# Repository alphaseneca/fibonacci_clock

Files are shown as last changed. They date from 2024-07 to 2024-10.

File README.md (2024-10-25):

<!-- # fibonacci_clock

A unique clock that uses the Fibonacci sequence to display time with colored squares, combining math and art in an innovative timekeeping design.

## Working

It works by lighing up a segment of the matrix based on the time in the Fibonacci sequence. If the time is 6:42 it will light up the segment **1** and **5** to **RED** which will add to give the hour 6. And for minutes it will light up the segment **3** and **5** to **BLUE** which will add to **8*5** equals to **40** minutes. And since the segment **5** are lit by both the hour and minutes it will change the colour to **GREEN** to show the overlap in the both hour and minutes.

> The segment can only represent between **1 - 12** and to represent the minutes we are multiplying it by 5.
> Since the increments are in every 5 minutes thus the time can be between **40 - 45** Minutes.

![fibonacci_clock](images/fibonacci_clock_working.jpg)

Working Image:
![fibonacci_clock](images/Image1.jpg)
 -->

# Fibonacci Clock

A unique clock project that combines **math and electronics** using the Fibonacci sequence to display time with colored segments. Powered by a **Wemos D1 Mini**, it fetches the current time using **NTP**. This repository serves as a **learning journal**, tracking the development process, inspirations, troubleshooting, and future improvements.

---

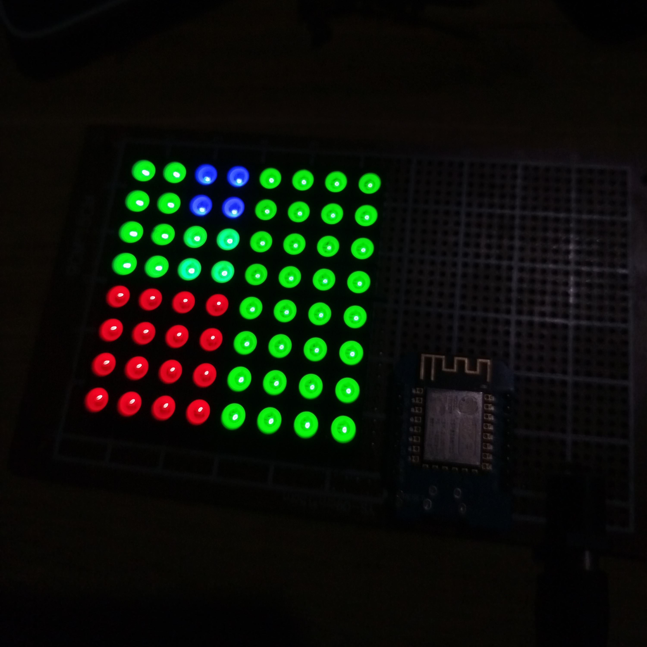
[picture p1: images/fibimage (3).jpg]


---

## Repository Structure

- **`images/`**: Photos of the clock and its working principle.
- **`fibonacci_clock_code/`**: Contains the code to run the Fibonacci clock logic.
<!-- - **`References/`**: Resources and ideas that inspired the project.   -->
- **`fibonacci_clock_pcb/`**: Files and documentation for the PCB design.
- **`debugging/`**: Logs of issues encountered and solutions applied during development.
<!-- - **`Inspiration.md`**: Notes on inspirations and design choices, with references for future enhancements. -->

---

## How It Works

The Fibonacci Clock displays time by lighting up segments of a matrix corresponding to Fibonacci numbers.

- **Microcontroller**: Wemos D1 Mini (ESP8266).
- **Time Sync**: Fetches the current time via **NTP** (Network Time Protocol).
- **Hour Representation**:  
  Example: If the time is **6:42**, segments **1** and **5** are lit **RED**, which sum to **6** for the hour.
- **Minute Representation**:  
  For **42 minutes**, segments **3** and **5** are lit **BLUE**, resulting in **(3 + 5) × 5 = 40 minutes**.
- **Overlap**:  
  When a segment represents both hours and minutes (e.g., segment **5**), it is lit **GREEN** to indicate overlap.

**Working Principle Diagram**:  
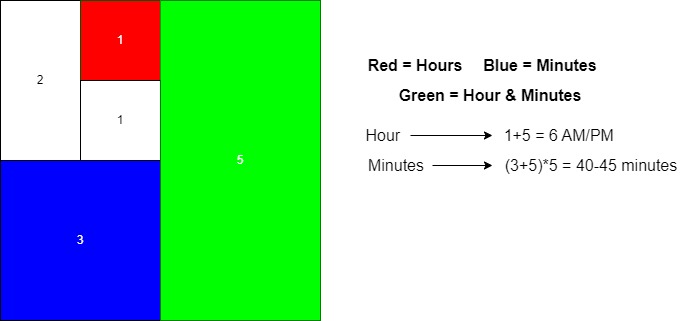
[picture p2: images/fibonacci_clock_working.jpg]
Fibonacci Clock Working
 

> Segments only represent numbers between **1 - 12**, and minute values are scaled by **multiplying by 5**.  
> Time increments are in 5-minute intervals, so valid minute values range between **40 - 45 minutes**.

---

## The Journey So Far

Building this clock has been an exciting adventure. It started as a simple idea to make a desktop artpiece that is bit unique and looks cool and ended up being a timekeeping device. Using the **Wemos D1 Mini** to sync time with NTP added complexity but opened new possibilities.

 <!-- Handling **network connectivity** and **color overlaps** provided valuable learning experiences. -->

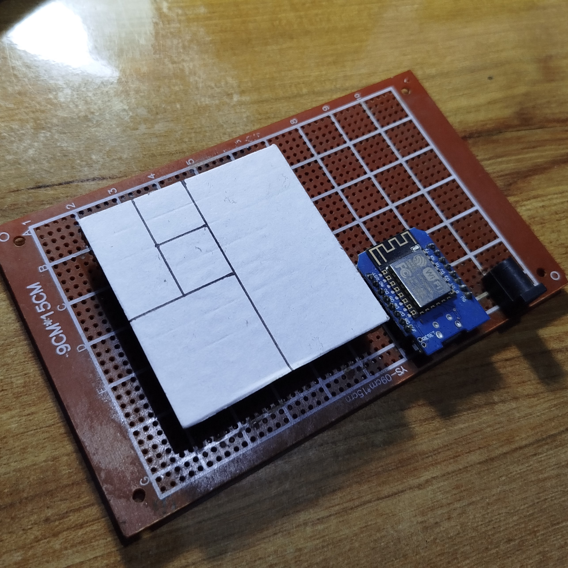
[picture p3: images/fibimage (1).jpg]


Creating the PCB design was also a journey in its own. I started with the prefboard and the main project is still on the prefboard but for the further development and to make the device look clean and more presentable the [PCB design](fibonacci_clock_pcb/fibonacci_clock_pcb.jpg) was created.

The pcb that I created is not complete. It is still a work in progress and nowhere near to the original design. I am planning to make the project like the main original design itself.

Future iterations may include **offline timekeeping** by integrating an **RTC module** to eliminate reliance on NTP. Wireless control and animations are also on the horizon!

---

## Debugging Log

- **Issue 1**: Incorrect color when hours and minutes overlapped.
  - **Solution**: Modified the RGB blending logic to correctly show GREEN for overlaps.
- **Issue 2**: Incorrect minute calculation when sum exceeded valid range.
  - **Solution**: Added checks to restrict values between 0-12 for valid Fibonacci sums.
- **Issue 3**: The light is not bright enough and flickers a lot.
  - **Solution**: Removed the delay in the main loop to reduce flickering.
    > Just a current solution though. Planning to remove the second solution in the future busing **MAX7219** chip rather than the **LM74HC595** chip.

---

## Future Improvements

- **RTC Integration**: Add an **RTC module** (like DS3231) for offline timekeeping.
- **PCB Enhancements**: Optimize the layout for smaller size and better wiring.
- **Dynamic Patterns**: Add animations or interactive light sequences. There could be much more animations and the rgb led can be used to show some patterns.
- **Battery Power**: Implement battery-powered functionality for portability.

---

## References and Inspirations

- Original inspiration from the [Kickstarter Campaign](https://www.kickstarter.com/projects/basbrun/fibonacci-clock-an-open-source-clock-for-nerds-wit).
- Building process from [Instructables project](https://www.instructables.com/The-Fibonacci-Clock/).
- Video from [Steve Ramsey on Youtube](https://www.youtube.com/watch?v=YIN95L4BdLk) building the clock .

<!-- [The guardian](https://www.theguardian.com/science/alexs-adventures-in-numberland/2015/may/09/fibonacci-clock-can-you-tell-the-time-on-the-worlds-most-stylish-nerd-timepiece) also covered the design of the fibonacci clock. -->

<!-- - Visual design inspired by [Fibonacci Artworks](https://example.com). -->

---

This repository will continue to evolve as I experiment with new features and improvements.

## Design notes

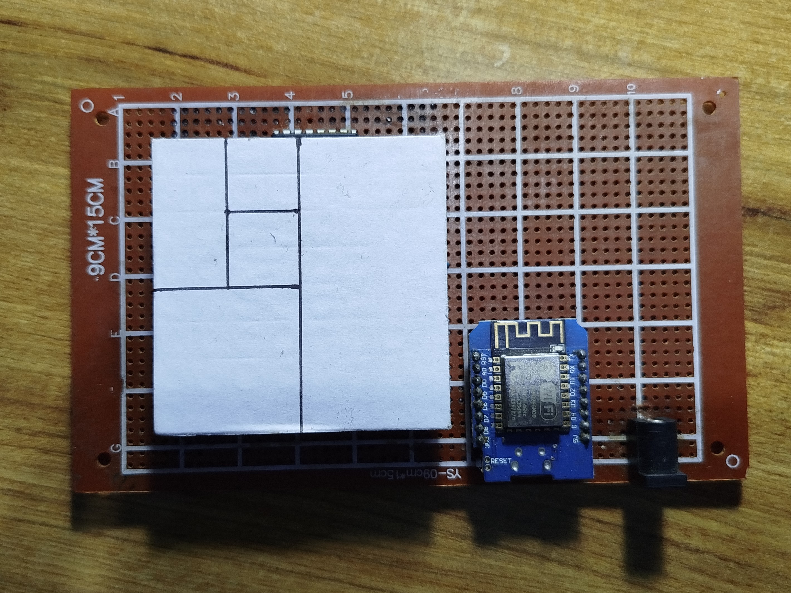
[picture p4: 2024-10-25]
images/fibimage (2).jpg

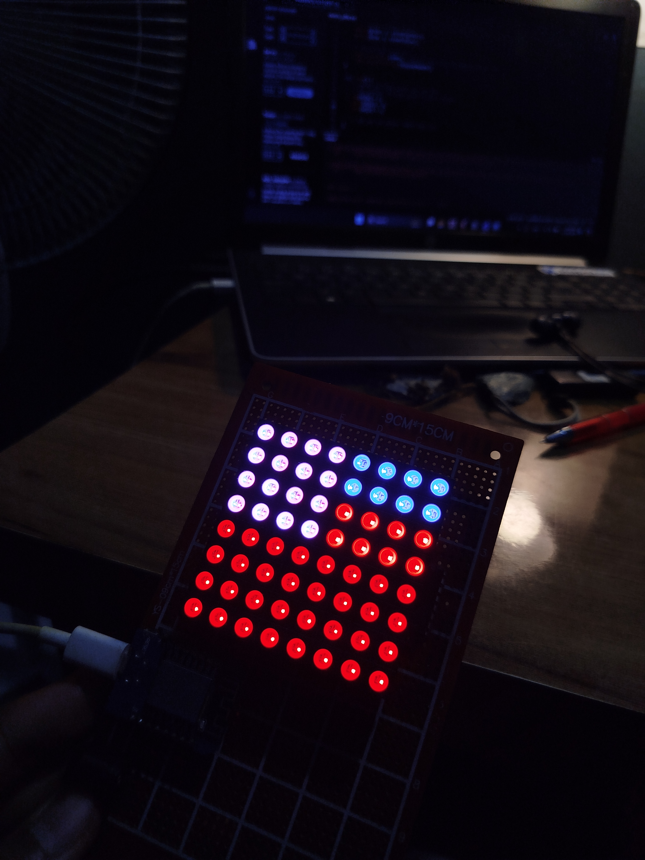
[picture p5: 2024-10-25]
images/fibimage (4).jpg

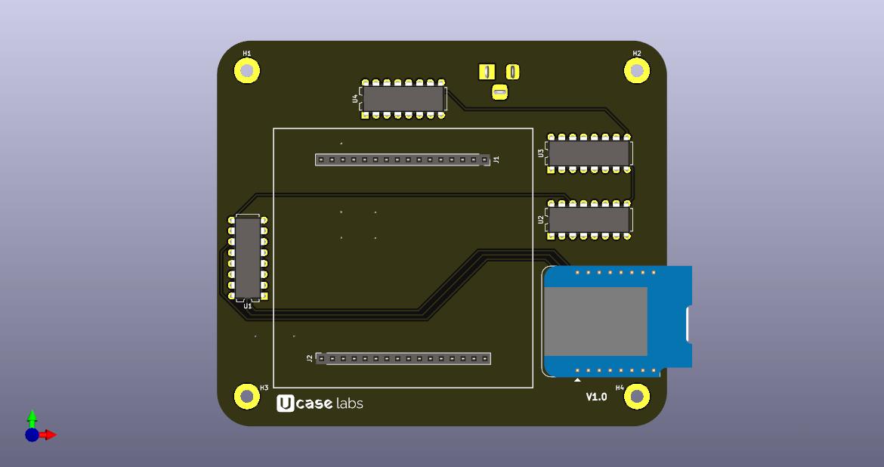
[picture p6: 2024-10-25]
fibonacci_clock_pcb/fibonacci_clock_pcb.jpg

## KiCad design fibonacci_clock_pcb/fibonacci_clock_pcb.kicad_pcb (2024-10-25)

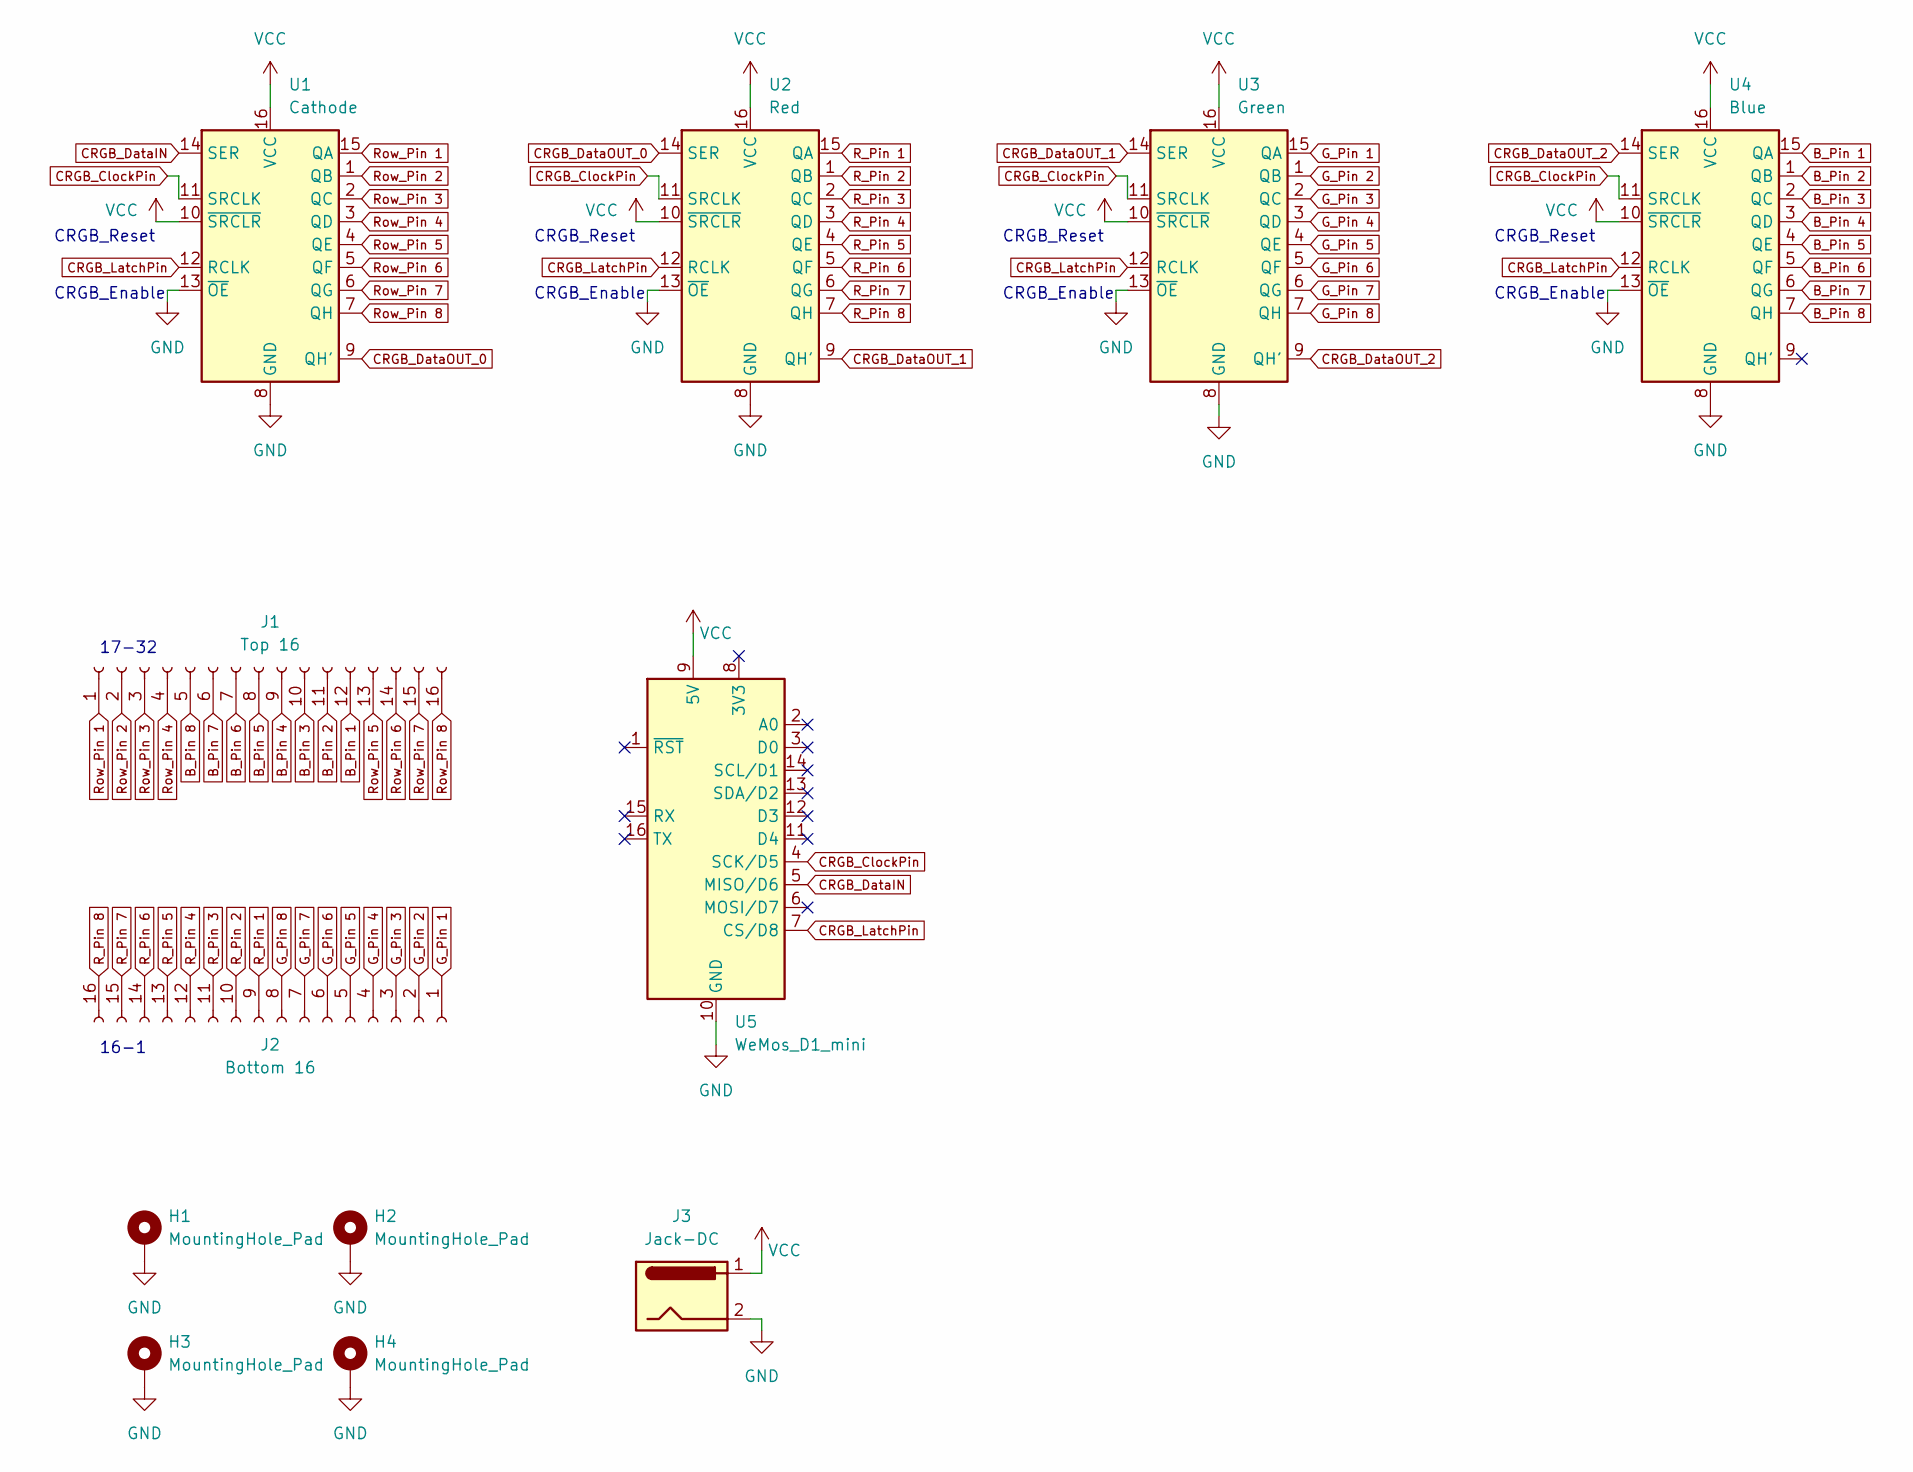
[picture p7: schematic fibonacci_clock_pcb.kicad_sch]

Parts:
H1, H2, H3, H4: MountingHole_Pad; MountingHole_3mm_Pad_TopBottom
J1: Top 16; PinSocket_1x16_P2.54mm_Vertical
J2: Bottom 16; PinSocket_1x16_P2.54mm_Vertical
J3: Jack-DC; BarrelJack_Horizontal
U1: Cathode; DIP-16_W7.62mm
U2: Red; DIP-16_W7.62mm
U3: Green; DIP-16_W7.62mm
U4: Blue; DIP-16_W7.62mm
U5: WeMos_D1_mini; WEMOS_D1_mini_light

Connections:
B_Pin 1: J1.12, U4.15 (QA)
B_Pin 2: J1.11, U4.1 (QB)
B_Pin 3: J1.10, U4.2 (QC)
B_Pin 4: J1.9, U4.3 (QD)
B_Pin 5: J1.8, U4.4 (QE)
B_Pin 6: J1.7, U4.5 (QF)
B_Pin 7: J1.6, U4.6 (QG)
B_Pin 8: J1.5, U4.7 (QH)
CRGB_ClockPin: U1.11 (SRCLK), U2.11 (SRCLK), U3.11 (SRCLK), U4.11 (SRCLK), U5.4 (SCK/D5)
CRGB_DataIN: U1.14 (SER), U5.5 (MISO/D6)
CRGB_DataOUT_0: U1.9 (QH'), U2.14 (SER)
CRGB_DataOUT_1: U2.9 (QH'), U3.14 (SER)
CRGB_DataOUT_2: U3.9 (QH'), U4.14 (SER)
CRGB_LatchPin: U1.12 (RCLK), U2.12 (RCLK), U3.12 (RCLK), U4.12 (RCLK), U5.7 (CS/D8)
GND: H1.1, H2.1, H3.1, H4.1, J3.2, U1.8 (GND), U1.13 (~OE), U2.8 (GND), U2.13 (~OE), U3.8 (GND), U3.13 (~OE), U4.8 (GND), U4.13 (~OE), U5.10 (GND)
G_Pin 1: J2.1, U3.15 (QA)
G_Pin 2: J2.2, U3.1 (QB)
G_Pin 3: J2.3, U3.2 (QC)
G_Pin 4: J2.4, U3.3 (QD)
G_Pin 5: J2.5, U3.4 (QE)
G_Pin 6: J2.6, U3.5 (QF)
G_Pin 7: J2.7, U3.6 (QG)
G_Pin 8: J2.8, U3.7 (QH)
R_Pin 1: J2.9, U2.15 (QA)
R_Pin 2: J2.10, U2.1 (QB)
R_Pin 3: J2.11, U2.2 (QC)
R_Pin 4: J2.12, U2.3 (QD)
R_Pin 5: J2.13, U2.4 (QE)
R_Pin 6: J2.14, U2.5 (QF)
R_Pin 7: J2.15, U2.6 (QG)
R_Pin 8: J2.16, U2.7 (QH)
Row_Pin 1: J1.1, U1.15 (QA)
Row_Pin 2: J1.2, U1.1 (QB)
Row_Pin 3: J1.3, U1.2 (QC)
Row_Pin 4: J1.4, U1.3 (QD)
Row_Pin 5: J1.13, U1.4 (QE)
Row_Pin 6: J1.14, U1.5 (QF)
Row_Pin 7: J1.15, U1.6 (QG)
Row_Pin 8: J1.16, U1.7 (QH)
VCC: J3.1, U1.10 (~SRCLR), U1.16 (VCC), U2.10 (~SRCLR), U2.16 (VCC), U3.10 (~SRCLR), U3.16 (VCC), U4.10 (~SRCLR), U4.16 (VCC), U5.9 (5V)

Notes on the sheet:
CRGB_Enable
CRGB_Reset
17-32
16-1

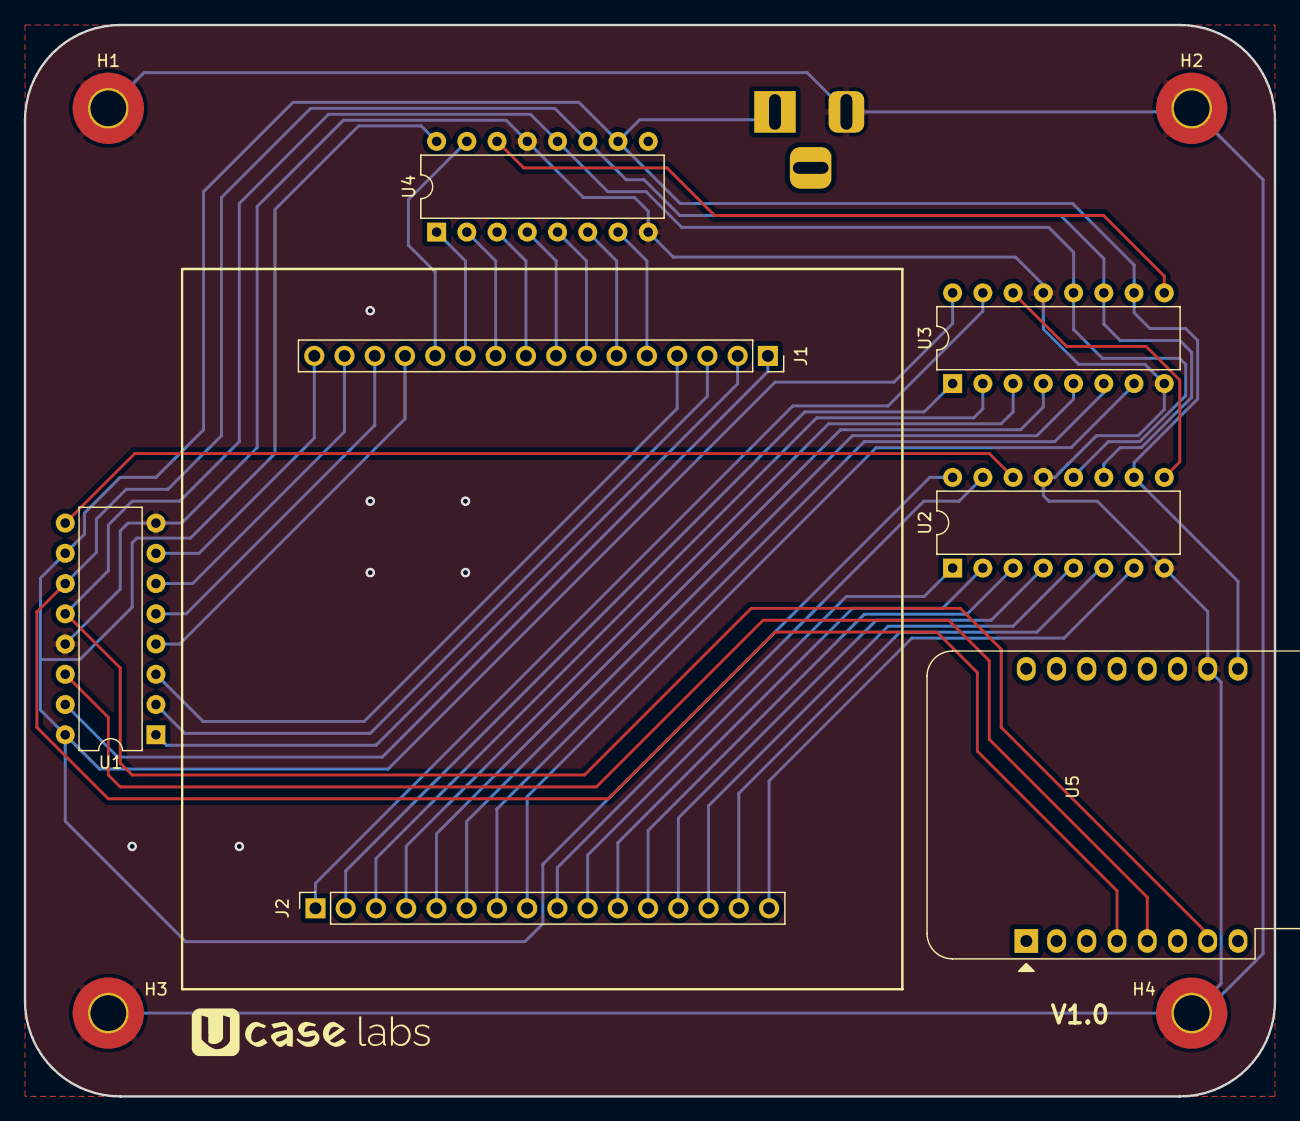
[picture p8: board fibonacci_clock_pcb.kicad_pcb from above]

Board: 2 copper layers, 105.0 x 90.0 mm, 12 parts (1 on the bottom side), 40 nets.

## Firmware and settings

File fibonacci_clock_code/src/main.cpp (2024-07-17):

#include <Arduino.h>
#include <secrets.h>
#include <ESP8266WiFi.h>
#include <ESP8266WebServer.h>
#include <DNSServer.h>
#include <WiFiManager.h>
#include <fibonacci_driver.h>
#include <ntptime.h>

// const char *ssid;
// const char *passphrase;

unsigned long currentTime1;
unsigned long timeElapsed1 = 0;
unsigned long currentTime2;
unsigned long timeElapsed2 = 0;
int hours;
int minutes;

const int resetpin = 1;

WiFiManager wm;
void setup(void)
{

  // Setup pins as Outputs
  pinMode(latchPin_CRGB, OUTPUT);
  pinMode(clockPin_CRGB, OUTPUT);
  pinMode(dataPin_CRGB, OUTPUT);
  // wm.resetSettings();
  // put your setup code here, to run once:
  Serial.begin(115200);
  bool wifistat;

  String SSID;
  String PASS;
  wifistat = wm.autoConnect("FiboArt Timepiece", "011235813");
  if (!wifistat)
  {
    Serial.println("Failed to connect");
  }

  else
  {
    Serial.println("connected...yeey :)");
    SSID = wm.getWiFiSSID();
    PASS = wm.getWiFiPass();
  }

  char ssid[SSID.length() + 1];
  char passphrase[PASS.length() + 1];

  strcpy(ssid, SSID.c_str());       //  Convert String to Char array
  strcpy(passphrase, PASS.c_str()); //  Convert String to Char array

  WiFi.begin(ssid, passphrase);

  while (WiFi.status() != WL_CONNECTED)
  {
    delay(500);
    Serial.print(".");
  }

  Serial.println("");
  Serial.print("Connected to ");
  Serial.println(ssid);
  Serial.print("IP address: ");
  Serial.println(WiFi.localIP());

  // Initialize a NTPClient to get time
  timeClient.begin();
}

String inputString = "";     // A string to hold incoming data
bool stringComplete = false; // Whether the string is complete
// Reserve 200 bytes for the inputString
// inputString.reserve(200);
// Function to handle the input string
unsigned long tracktime;
void loop()
{
  // Check if the string is complete
  // if (stringComplete)
  // {
  //   // Call the function with the input string
  //   handleInput(inputString);
  //   // Clear the string
  //   inputString = "";
  //   stringComplete = false;
  // }

  if (digitalRead(resetpin) == HIGH)
  {
    wm.resetSettings();
    delay(2000);
    ESP.reset();
  }
  currentTime1 = millis();
  if (currentTime1 - timeElapsed1 >= 10000)
  {
    timeElapsed1 = currentTime1;
    fetchTime();
    minutes = timeClient.getMinutes();
    minutes = minutes / 5;
    hours = timeClient.getHours();
    hours = (hours > 12) ? hours - 12 : hours;
  }
  displayTime(hours, minutes);
  // currentTime2 = micros();
  // if (currentTime2 - timeElapsed2 >= 100)
  // {
  //   timeElapsed2 = currentTime2;
  // }
  // int minutes = timeClient.getSeconds();
  // int hours = timeClient.getHours();
  // displayTime({(hours > 12 ? hours - 12 : hours)}, minutes / 5);
  // timeClient.update();
}
